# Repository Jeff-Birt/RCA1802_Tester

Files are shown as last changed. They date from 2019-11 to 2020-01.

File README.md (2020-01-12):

# RCA1802_Tester
Using an Aruino Mega 2560 to test RCA/Harris/Intersil 1802 processors

I boughtt a batch of old RCA 1802 micro-processors from C.H. Ina & Company on eBay. When they showed up it was obvious that had been sanded and re-labeled. The rest of the parts for the project I wanted them for had not arrived and I wanted to test them before complaining.

I had an Arduino Mega 2560 sitting on the bench and thought I would try to use it to test the 1802s. This project is the result of that effort...

NOTE:
 PCB Design, button handling code, and EF randomization code from: Hans Liss, Thanks Hans!

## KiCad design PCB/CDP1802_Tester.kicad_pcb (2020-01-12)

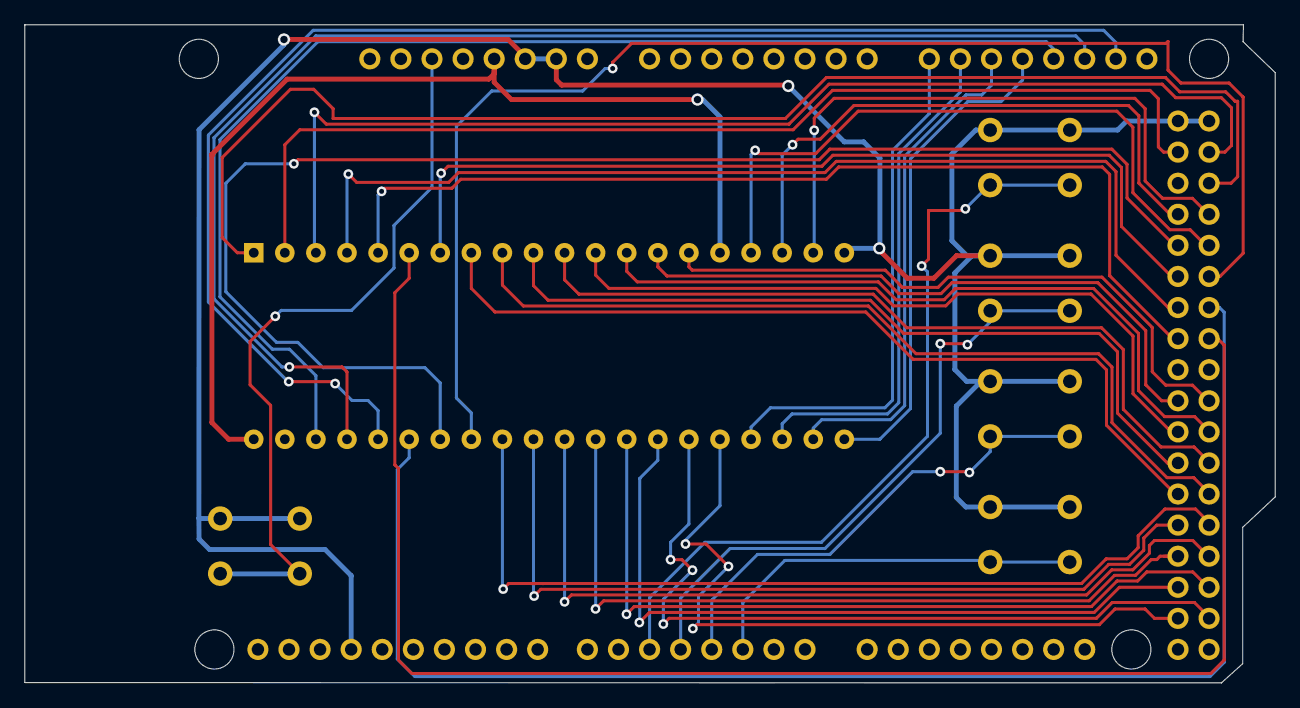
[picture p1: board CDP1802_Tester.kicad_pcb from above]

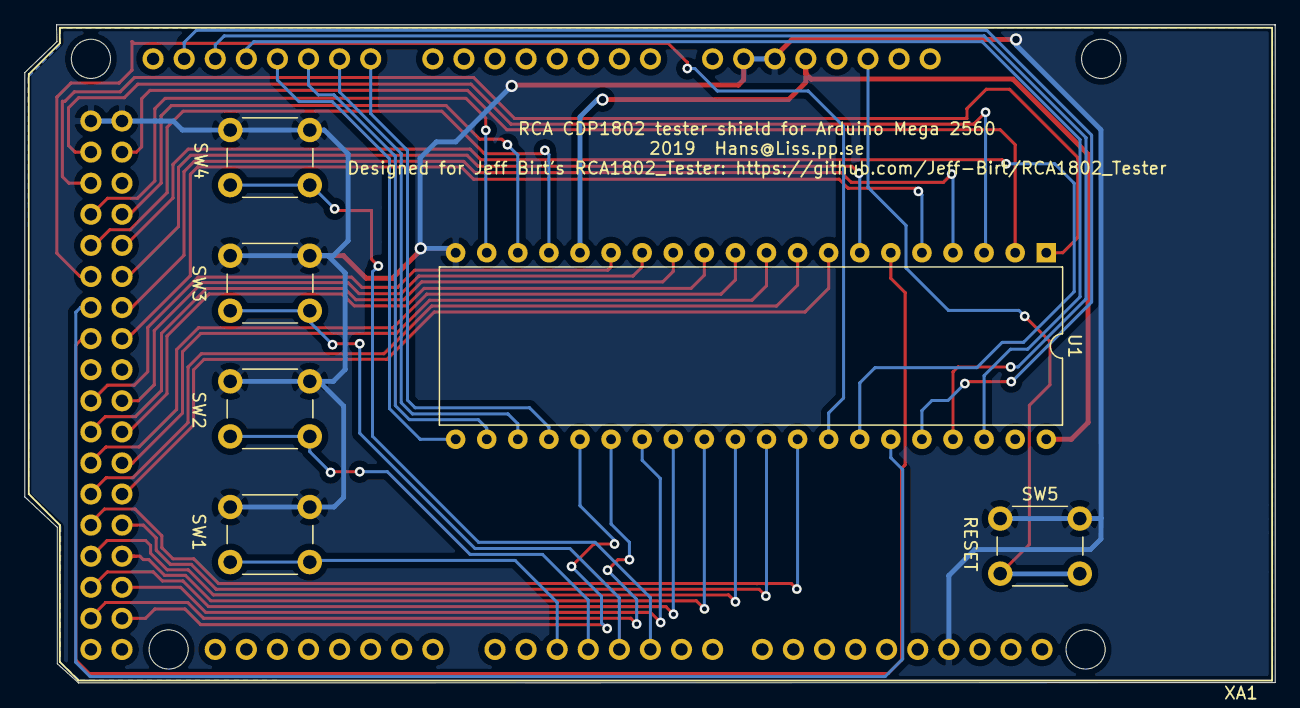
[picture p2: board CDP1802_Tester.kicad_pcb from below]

Board: 2 copper layers, 102.2 x 53.8 mm, 7 parts (7 on the bottom side), 43 nets.

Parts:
SW1, SW2, SW3, SW4, SW5: SW_Push; SW_PUSH_6mm
U1: CDP1802ACE; DIP-40_W15.24mm
XA1: Arduino_Mega2560_Shield_alt1

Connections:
/CLEAR: U1.3, XA1.D53
/CLOCK: U1.1, XA1.D51
/D0: U1.15, XA1.D37
/D1: U1.14, XA1.D36
/D2: U1.13, XA1.D35
/D3: U1.12, XA1.D34
/D4: U1.11, XA1.D33
/D5: U1.10, XA1.D32
/D6: U1.9, XA1.D31
/D7: U1.8, XA1.D30
/DMA_IN: U1.38, XA1.A12
/DMA_OUT: U1.37, XA1.A13
/EF1: U1.24, XA1.A8
/EF2: U1.23, XA1.A9
/EF3: U1.22, XA1.A10
/EF4: U1.21, XA1.A11
/INTERRUPT: U1.36, XA1.A14
/MA0: U1.25, XA1.D22
/MA1: U1.26, XA1.D23
/MA2: U1.27, XA1.D24
/MA3: U1.28, XA1.D25
/MA4: U1.29, XA1.D26
/MA5: U1.30, XA1.D27
/MA6: U1.31, XA1.D28
/MA7: U1.32, XA1.D29
/MRD: U1.7, XA1.D44
/MWR: U1.35, XA1.D43
/N0: U1.19, XA1.D49
/N1: U1.18, XA1.D48
/N2: U1.17, XA1.D47
/Q: U1.4, XA1.D42
/SC0: U1.6, XA1.D41
/SC1: U1.5, XA1.D40
/TPA: U1.34, XA1.D46
/TPB: U1.33, XA1.D45
/WAIT: U1.2, XA1.D52
GND: SW1.2, SW2.2, SW3.2, SW4.2, SW5.1, U1.20, XA1.GND1, XA1.GND2, XA1.GND3, XA1.GND5, XA1.GND6
unnamed: SW1.1, XA1.D2
unnamed: SW2.1, XA1.D3
unnamed: SW3.1, XA1.D4
unnamed: SW4.1, XA1.D5
unnamed: SW5.2, XA1.RST1
VCC: U1.16, U1.40, XA1.5V1

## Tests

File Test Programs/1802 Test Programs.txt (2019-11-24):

LDI 0x0F
PLO R(1).0
LDI 0x00
PHI R(1).1
SEX R1
LDI 0x55
STR R1

// Memory store --- Load D with 0x55 store to Address pointed to by R(1)
// virtual system RAM, 0x0000 to 0x0039 ->
byte virtRAM[] =  { 0xF8, 0x0F, 0xA1, 0xF8, 0x00, 0xB1, 0xE1, 0xF8,
					0x55, 0x51, 0xC4, 0xC4, 0xC4, 0xC4, 0xC4, 0xC4,
					0xC4, 0xC4, 0xC4, 0xC4, 0xC4, 0xC4, 0xC4, 0xC4,
					0xC4, 0xC4, 0xC4, 0xC4, 0xC4, 0xC4, 0xC4, 0xC4,
					0xC4, 0xC4, 0xC4, 0xC4, 0xC4, 0xC4, 0xC4, 0xC4,
					0xC4, 0xC4, 0xC4, 0xC4, 0xC4, 0xC4, 0xC4, 0xC4,
					0xC4, 0xC4, 0xC4, 0xC4, 0xC4, 0xC4, 0xC4, 0xC4,
					0xC4, 0xC4, 0xC4, 0xC4, 0xC4, 0xC4, 0xC4, 0xC4 };

LDI 0x0F
PLO R(1).0
LDI 0x00
PHI R(1).1
SEX R1
OUT 1

// I/O Output --- Set R(1)=0x000F, Set X=R(1), Mem @ R(1) output to data bus
// N0, N1, N2 indicate the lower nibble of the 6N Output instruction
// virtual system RAM, 0x0000 to 0x0039 -> 
byte virtRAM[] =  { 0xF8, 0x0F, 0xA1, 0xF8, 0x00, 0xB1, 0xE1, 0x61,
					0xC4, 0xC4, 0xC4, 0xC4, 0xC4, 0xC4, 0xC4, 0x55,
					0xC4, 0xC4, 0xC4, 0xC4, 0xC4, 0xC4, 0xC4, 0xC4,
					0xC4, 0xC4, 0xC4, 0xC4, 0xC4, 0xC4, 0xC4, 0xC4,
					0xC4, 0xC4, 0xC4, 0xC4, 0xC4, 0xC4, 0xC4, 0xC4,
					0xC4, 0xC4, 0xC4, 0xC4, 0xC4, 0xC4, 0xC4, 0xC4,
					0xC4, 0xC4, 0xC4, 0xC4, 0xC4, 0xC4, 0xC4, 0xC4,
					0xC4, 0xC4, 0xC4, 0xC4, 0xC4, 0xC4, 0xC4, 0xC4 };

LDI 0x0F
PLO R(1).0
LDI 0x00
PHI R(1).1
SEX R1
INP 1

// I/O Input --- Set R(1)=0x000F, Set X=R(1), Input from data bus to Mem @ R(1)
// N0, N1, N2 indicate the lower nibble of the 6N Output instruction
// virtual system RAM, 0x0000 to 0x0039 -> 
byte virtRAM[] =  { 0xF8, 0x0F, 0xA1, 0xF8, 0x00, 0xB1, 0xE1, 0x69,
					0xC4, 0xC4, 0xC4, 0xC4, 0xC4, 0xC4, 0xC4, 0x55,
					0xC4, 0xC4, 0xC4, 0xC4, 0xC4, 0xC4, 0xC4, 0xC4,
					0xC4, 0xC4, 0xC4, 0xC4, 0xC4, 0xC4, 0xC4, 0xC4,
					0xC4, 0xC4, 0xC4, 0xC4, 0xC4, 0xC4, 0xC4, 0xC4,
					0xC4, 0xC4, 0xC4, 0xC4, 0xC4, 0xC4, 0xC4, 0xC4,
					0xC4, 0xC4, 0xC4, 0xC4, 0xC4, 0xC4, 0xC4, 0xC4,
					0xC4, 0xC4, 0xC4, 0xC4, 0xC4, 0xC4, 0xC4, 0xC4 };

REQ
LDI 0x10
PLO R(1).0
LDI 0x00
PHI R(1).1
DEC R1
GLO R1
BNZ 0x07
BQ  0x00
SEQ
BR  0x01

// Q blink --- Q off, load 0x0010 to R(1)
// virtual system RAM, 0x0000 to 0x0039 -> 
byte virtRAM[] = {	0x7A, 0xF8, 0x10, 0xA1, 0xF8, 0x00, 0xB1, 0x21,
					0x81, 0x3A, 0x07, 0x31, 0x00, 0x7B, 0x30, 0x01,
					0xC4, 0xC4, 0xC4, 0xC4, 0xC4, 0xC4, 0xC4, 0xC4, 
					0xC4, 0xC4, 0xC4, 0xC4, 0xC4, 0xC4, 0xC4, 0xC4, 
					0xC4, 0xC4, 0xC4, 0xC4, 0xC4, 0xC4, 0xC4, 0xC4, 
					0xC4, 0xC4, 0xC4, 0xC4, 0xC4, 0xC4, 0xC4, 0xC4, 
					0xC4, 0xC4, 0xC4, 0xC4, 0xC4, 0xC4, 0xC4, 0xC4, 
					0xC4, 0xC4, 0xC4, 0xC4, 0xC4, 0xC4, 0xC4, 0xC4 };

00	F8 22	LDI 0x0F
02	A1		PLO R(1).0
03	F8 00	LDI 0x00
05	B1		PHI R(1).1
06	E1		SEX R1
07	34 11	B1 	0x11	'EF1
09	35 15	B2	0x15	'EF2
0B	36 19	B3	0x19	'EF3
0D	37 1D	B4	0x1D	'EF4
0F	30 07	BR  0x07
11	F8 01	LDI	0x01
13	30 1F	BR	0x1F	'OUTPUT
15	F8 02	LDI 0x02
17	30 1F	BR 	0x1F	'OUTPUT
19	F8 03	LDI 0x03
1B	30 1F	BR	0x1F	'OUTPUT
1D	F8 04	LDI	0x04
1F	51		STR R1		'OUTPUT
20	30 07	BR	0x07

// EFx input test -- output EF input # to Memory @ 0x22
// virtual system RAM, 0x0000 to 0x0039 -> 
byte virtRAM[] = {	0xF8, 0x22, 0xA1, 0xF8, 0x00, 0xB1, 0xE1, 0x34,
					0x11, 0x35, 0x15, 0x36, 0x19, 0x37, 0x1D, 0x30,
					0x07, 0xF8, 0x01, 0x30, 0x1F, 0xF8, 0x02, 0x30, 
					0x1F, 0xF8, 0x03, 0x30, 0x1F, 0xF8, 0x04, 0x51, 
					0x30, 0x07, 0xC4, 0xC4, 0xC4, 0xC4, 0xC4, 0xC4, 
					0xC4, 0xC4, 0xC4, 0xC4, 0xC4, 0xC4, 0xC4, 0xC4, 
					0xC4, 0xC4, 0xC4, 0xC4, 0xC4, 0xC4, 0xC4, 0xC4, 
					0xC4, 0xC4, 0xC4, 0xC4, 0xC4, 0xC4, 0xC4, 0xC4 };

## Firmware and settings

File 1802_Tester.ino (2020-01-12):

/*
 Simple test program for RCA 1802 microprocessor
 Jeffrey T. Birt (Hey Birt!)
 website: http://www.soigeneris.com
 YouTube: http://www.youtube.com/c/HeyBirt

 PCB Design, button handling code, and EF ran. from: Hans Liss, Thanks Hans!
*/

// NOTES: Uses a Arduino Mega 2560
// control /CLR and /WAIT 
// what should the settings for debug view levels be?
// A) full instruction cycle
// B) every half clock
// C) memory read/write
// D) I/O input/output

#include "1802_Tester.h"

// Arduino system states
enum SYS_STATE
{
	SYS_INIT,		// Initialized I/O, do start delay
	SYS_RESET,		// RESET mode: /CLEAR  WAIT
	SYS_PAUSE,		// PAUSE mode:  CLEAR /WAIT
	SYS_RUN,		// RUN mode:    CLEAR  WAIT
	SYS_STEP,		// Process one opcocde then STOP mode
	SYS_STOP		// stock clock
};

// States the control singnals can be in
enum SIGNAL_STATE
{
	SIG_LOW,
	SIG_RISING,
	SIG_HIGH,
	SIG_FALLING
};

enum DEBUG_STATE
{
	DB_OFF,
	DB_MININUM,
	DB_VERBOSE
};

#pragma region "1802 Test Programs"

// Memory store --- Load D with 0x55 store to Address pointed to by R(1)
// virtual system RAM, 0x0000 to 0x0039 ->
//byte virtRAM[] =  { 0xF8, 0x0F, 0xA1, 0xF8, 0x00, 0xB1, 0xE1, 0xF8,
//					0x55, 0x51, 0xC4, 0xC4, 0xC4, 0xC4, 0xC4, 0xC4,
//					0xC4, 0xC4, 0xC4, 0xC4, 0xC4, 0xC4, 0xC4, 0xC4,
//					0xC4, 0xC4, 0xC4, 0xC4, 0xC4, 0xC4, 0xC4, 0xC4,
//					0xC4, 0xC4, 0xC4, 0xC4, 0xC4, 0xC4, 0xC4, 0xC4,
//					0xC4, 0xC4, 0xC4, 0xC4, 0xC4, 0xC4, 0xC4, 0xC4,
//					0xC4, 0xC4, 0xC4, 0xC4, 0xC4, 0xC4, 0xC4, 0xC4,
//					0xC4, 0xC4, 0xC4, 0xC4, 0xC4, 0xC4, 0xC4, 0xC4 };


// I/O Output --- Set R(1)=0x000F, Set X=R(1), Mem @ R(1) output to data bus
// N0, N1, N2 indicate the lower nibble of the 6N Output instruction
// virtual system RAM, 0x0000 to 0x0039 -> 
//byte virtRAM[] =  { 0xF8, 0x0F, 0xA1, 0xF8, 0x00, 0xB1, 0xE1, 0x61,
//					0xC4, 0xC4, 0xC4, 0xC4, 0xC4, 0xC4, 0xC4, 0x55,
//					0xC4, 0xC4, 0xC4, 0xC4, 0xC4, 0xC4, 0xC4, 0xC4,
//					0xC4, 0xC4, 0xC4, 0xC4, 0xC4, 0xC4, 0xC4, 0xC4,
//					0xC4, 0xC4, 0xC4, 0xC4, 0xC4, 0xC4, 0xC4, 0xC4,
//					0xC4, 0xC4, 0xC4, 0xC4, 0xC4, 0xC4, 0xC4, 0xC4,
//					0xC4, 0xC4, 0xC4, 0xC4, 0xC4, 0xC4, 0xC4, 0xC4,
//					0xC4, 0xC4, 0xC4, 0xC4, 0xC4, 0xC4, 0xC4, 0xC4 };


// I/O Input --- Set R(1)=0x000F, Set X=R(1), Input from data bus to Mem @ R(1)
// N0, N1, N2 indicate the lower nibble of the 6N Output instruction
// virtual system RAM, 0x0000 to 0x0039 -> 
//byte virtRAM[] =  { 0xF8, 0x0F, 0xA1, 0xF8, 0x00, 0xB1, 0xE1, 0x69,
//					0xC4, 0xC4, 0xC4, 0xC4, 0xC4, 0xC4, 0xC4, 0x55,
//					0xC4, 0xC4, 0xC4, 0xC4, 0xC4, 0xC4, 0xC4, 0xC4,
//					0xC4, 0xC4, 0xC4, 0xC4, 0xC4, 0xC4, 0xC4, 0xC4,
//					0xC4, 0xC4, 0xC4, 0xC4, 0xC4, 0xC4, 0xC4, 0xC4,
//					0xC4, 0xC4, 0xC4, 0xC4, 0xC4, 0xC4, 0xC4, 0xC4,
//					0xC4, 0xC4, 0xC4, 0xC4, 0xC4, 0xC4, 0xC4, 0xC4,
//					0xC4, 0xC4, 0xC4, 0xC4, 0xC4, 0xC4, 0xC4, 0xC4 };


// EFx input test -- output EF input # to Memory @ 0x22
// virtual system RAM, 0x0000 to 0x0039 -> 
byte virtRAM[] = {  0xF8, 0x22, 0xA1, 0xF8, 0x00, 0xB1, 0xE1, 0x34,
					0x11, 0x35, 0x15, 0x36, 0x19, 0x37, 0x1D, 0x30,
					0x07, 0xF8, 0x01, 0x30, 0x1F, 0xF8, 0x02, 0x30,
					0x1F, 0xF8, 0x03, 0x30, 0x1F, 0xF8, 0x04, 0x51,
					0x30, 0x07, 0xC4, 0xC4, 0xC4, 0xC4, 0xC4, 0xC4,
					0xC4, 0xC4, 0xC4, 0xC4, 0xC4, 0xC4, 0xC4, 0xC4,
					0xC4, 0xC4, 0xC4, 0xC4, 0xC4, 0xC4, 0xC4, 0xC4,
					0xC4, 0xC4, 0xC4, 0xC4, 0xC4, 0xC4, 0xC4, 0xC4 };

// Q blink --- Q off, load 0x0010 to R(1)
// virtual system RAM, 0x0000 to 0x0039 -> 
//byte virtRAM[] = {	0x7A, 0xF8, 0x10, 0xA1, 0xF8, 0x00, 0xB1, 0x21,
//					0x81, 0x3A, 0x07, 0x31, 0x00, 0x7B, 0x30, 0x01,
//					0xC4, 0xC4, 0xC4, 0xC4, 0xC4, 0xC4, 0xC4, 0xC4, 
//					0xC4, 0xC4, 0xC4, 0xC4, 0xC4, 0xC4, 0xC4, 0xC4, 
//					0xC4, 0xC4, 0xC4, 0xC4, 0xC4, 0xC4, 0xC4, 0xC4, 
//					0xC4, 0xC4, 0xC4, 0xC4, 0xC4, 0xC4, 0xC4, 0xC4, 
//					0xC4, 0xC4, 0xC4, 0xC4, 0xC4, 0xC4, 0xC4, 0xC4, 
//					0xC4, 0xC4, 0xC4, 0xC4, 0xC4, 0xC4, 0xC4, 0xC4 };

// NOP test - Simple NOP test, address should increase
// virtual system RAM, 0x0000 to 0x0039 -> 
//byte virtRAM[] = {	0xC4, 0xC4, 0xC4, 0xC4, 0xC4, 0xC4, 0xC4, 0xC4,
//					0xC4, 0xC4, 0xC4, 0xC4, 0xC4, 0xC4, 0xC4, 0xC4,
//					0xC4, 0xC4, 0xC4, 0xC4, 0xC4, 0xC4, 0xC4, 0xC4, 
//					0xC4, 0xC4, 0xC4, 0xC4, 0xC4, 0xC4, 0xC4, 0xC4, 
//					0xC4, 0xC4, 0xC4, 0xC4, 0xC4, 0xC4, 0xC4, 0xC4, 
//					0xC4, 0xC4, 0xC4, 0xC4, 0xC4, 0xC4, 0xC4, 0xC4, 
//					0xC4, 0xC4, 0xC4, 0xC4, 0xC4, 0xC4, 0xC4, 0xC4, 
//					0xC4, 0xC4, 0xC4, 0xC4, 0xC4, 0xC4, 0xC4, 0xC4 };

#pragma endregion "1802 Test Programs"

// gloabls
int Start_Delay = 0;		// delay reset release 64 half clocks after start
unsigned int Address16 = 0; // used to latch in full 16-bit address
unsigned int clkCount = 0;	// counts in 1/2 clock cycles
SYS_STATE sysState = SYS_INIT;
SIGNAL_STATE MRD_State = SIG_LOW;
SIGNAL_STATE MWR_State = SIG_LOW;
SIGNAL_STATE TPA_State = SIG_LOW;
SIGNAL_STATE TPB_State = SIG_LOW;
DEBUG_STATE debugState = DB_MININUM;

byte newPORTA = 0; byte oldPORTA = 0;	// not sure if oldPORTA actually needed
byte newPORTL = 0; byte oldPORTL = 0;	// track old state, compare to new for rising/falling edges
byte newSCx = 0; 						// new state of SC0 adn SC1

unsigned long debounceDelay = 50;    // the debounce time; increase if the output flickers

// Initalize the Arduino I/O ports, start serial coms
// Leave processer in RESET mode: /CLEAR WAIT
void setup()
{
	PORTA = PORTA & ~ADD_BUS;	  // all pins low for HIZ
	PORTB = ( PORTB & ~(CLEAR | CLOCK) ) | WAIT; // set to reset mode
	PORTC = PORTC & ~DATA_BUS;	  // all pins low for HIZ
	PORTG = PORTG & ~(SC0 | SC1); // all pins low for HIZ
	PORTK = PORTK | (EF1 | EF2 | EF3 | EF4 | DMA_IN | DMA_OUT | INTERRUPT); // all pins HI/off
	PORTL = PORTL & ~(N0 | N1 | N2 | TPA | TPB | MRD | MWR | Q); // all pins low for HIZ

	DDRA = ~ADD_BUS;	// all inputs, HIZ at this point
	DDRB = CLEAR | WAIT | CLOCK; // outputs
	DDRC = ~DATA_BUS;	// all inputs, HIZ at this point
	DDRG = DDRG & ~(SC0 | SC1);  // inputs, HIZ at this point
	DDRK = EF1 | EF2 | EF3 | EF4 | DMA_IN | DMA_OUT | INTERRUPT; // outputs, all HI at this point
	DDRL = ~(N0 | N1 | N2 | TPA | TPB | MRD | MWR | Q); // all inputs, HIZ at this point

	initButtons();

	Serial.begin(19200); // open the serial port at 9600 bps:
	Serial.println("Starting...");
}


// Start up in RESET mode, start clock, after 64 clocks put in PAUSE mode
// Clock count only incremetned in RUN mode.
void loop()
{
	readButtons();
	// watch for input from user here, using a blocking read for now
	if (Serial.available())
	{
		String command = Serial.readStringUntil('\n');
		cmdDecode(command);
	}

	if (sysState == SYS_RUN)
	{
		if (hasButtonPressEvent(0)) {
			randomize_ef();
		}
    
		// read in current state of I/O
		newPORTA = PINA;			 // 1802 address bus
		newPORTL = PINL;			 // 1802 status outputs
		newSCx = PING & (SC0 | SC1); // 1802 state outputs

		// (A) Decode state of control signals
		stateDecode();

		// (B) Address latch, rising edge TPA latch MSB, rising edge TPB latch LSB
		if (TPA_State == SIG_RISING)
		{
			Address16 = newPORTA;
			//logState("TPA");
		} 
		else if (TPB_State == SIG_RISING)
		{
			Address16 = (Address16 << 8) | newPORTA;
			//logState("TPB");
		}

		// (C) if rising edge of /MRD or /MWR then set data bus to input from 1802
		if ((MRD_State == SIG_RISING) | (MWR_State == SIG_RISING))
		{
			portC_ModeInput();
			logState("Data bus Input");
		}

		// (D) TPB rising edge, reading (Arduino to 1802), or writing (1802 to Arduino)
		// if /MRD low Arduino writing to data bus, 1802 reading from memory
		// Arduino reading data from data bus, i.e. 1802 is writing to virtual memory
		if (TPB_State == SIG_RISING)
		{
			if (MRD_State == SIG_LOW)
			{
				portC_ModeOutput();

				if (Address16 < 64)
				{
					portC_OutputValue(virtRAM[Address16]);
					logState("1802 Memory Read");
				}
				else
				{
					portC_OutputValue(0xC4); // NOP
					logState("NOP");
				}
			}
			else if (MWR_State == SIG_LOW)
			{
				byte fromDataBus = portC_InputValue();
				if (Address16 < 64)
				{
					virtRAM[Address16] = fromDataBus;
				}
				logState(String(fromDataBus, HEX) + " 1802 Memory Write");
			}
		}

		// (E) reading or writing to I/O port if N0~N2 raised and
		// /MRW falling edge indicates input from Arduino to 1802, 
		// /MRD and TPB rising edge indicates output from 1802 to Arduino
		if (newPORTL & (N0 | N1 | N2))
		{
			if (MWR_State == SIG_FALLING)
			{
				portC_ModeOutput();
				portC_OutputValue(0xAA); // fixed value at this point
				logState(" I/O Input");
			}
			else if (MRD_State == SIG_LOW && TPB_State == SIG_RISING)
			{
				byte fromDataBus = portC_InputValue();
				logState(String(fromDataBus, HEX) + " I/O Output");
			}
		}

		// (F) Is Q rising or falling?
		if ((newPORTL & Q) && !(oldPORTL & Q))
		{
			logState("Q turned on");
		}
		else if (!(newPORTL & Q) && (oldPORTL & Q))
		{
			logState("Q turned off");
		}

		delay(100);				// delay for serial debug display
		clkCount++;				// inc clock 1/2 tick
		oldPORTA = newPORTA;	// not sure I need to save address bus
		oldPORTL = newPORTL;	// save new values for comparison next cycle
	}
	else if (sysState == SYS_INIT)
	{
		Start_Delay++;
		if (Start_Delay > 63)
		{
			//PORTB = PORTB | CLEAR;  // PAUSE mode:  CLEAR /WAIT
			//PORTB = PORTB & ~WAIT;	//
			//sysState = SYS_PAUSE;
			//Serial.println("");
			//Serial.println("Pause Mode");
			cmdDecode("pause");
		}
	}

	if (sysState != SYS_STOP)
	{
		PORTB = PORTB ^ CLOCK; // toggle clock 1/2 tick
	}
}

// Decodes state (rising/falling/steady) of control signals
void stateDecode()
{
	if (newPORTL & TPA)
	{
		TPA_State = (!(oldPORTL & TPA)) ? SIG_RISING : SIG_HIGH;
	}
	else
	{
		TPA_State = (oldPORTL & TPA) ? SIG_FALLING : SIG_LOW;
	}

	if (newPORTL & TPB)
	{
		TPB_State = (!(oldPORTL & TPB)) ? SIG_RISING : SIG_HIGH;
	}
	else
	{
		TPB_State = (oldPORTL & TPB) ? SIG_FALLING : SIG_LOW;
	}

	if (newPORTL & MRD)
	{
		MRD_State = (!(oldPORTL & MRD)) ? SIG_RISING : SIG_HIGH;
		//logState("MRD " + String((MRD_State == SIG_RISING)?"RISING":"HIGH"));
	}
	else
	{
		MRD_State = (oldPORTL & MRD) ? SIG_FALLING : SIG_LOW;
		//logState("MRD " + String((MRD_State == SIG_FALLING)?"FALLING":"LOW"));
	}

	if (newPORTL & MWR)
	{
		MWR_State = (!(oldPORTL & MWR)) ? SIG_RISING : SIG_HIGH;
		//logState("MWR " + String((MWR_State == SIG_RISING)?"RISING":"HIGH"));
	}
	else
	{
		MWR_State = (oldPORTL & MWR) ? SIG_FALLING : SIG_LOW;
		//logState("MWR " + String((MWR_State == SIG_FALLING)?"FALLING":"LOW"));
	}
}

// wonder if this should be used for changing states as well?
void cmdDecode(String command)
{
	if (command == "load")
	{
		// Control bits: /CLEAR /WAIT
		Serial.println();
		Serial.println("Load Mode");
	}
	else if (command == "reset")
	{
		PORTB = PORTB & ~CLEAR; // RESET mode:  /CLEAR WAIT
		PORTB = PORTB | WAIT;	//
		sysState = SYS_RESET;

		Serial.println();
		Serial.println("Reset Mode");
	}
	else if (command == "pause")
	{
		PORTB = PORTB | CLEAR;  // PAUSE mode:  CLEAR /WAIT
		PORTB = PORTB & ~WAIT;	//
		sysState = SYS_PAUSE;
		Serial.println();
		Serial.println("Pause Mode");
	}
	else if (command == "run")
	{
		// start clock so processor and/or set to RUN mode
		PORTB = PORTB | CLEAR;  // RUN mode:  CLEAR WAIT
		PORTB = PORTB | WAIT;	//
		sysState = SYS_RUN;

		Serial.println();
		Serial.println("Run mode");
		Serial.println("Clk \tSCx \tCW_CL \tPORTL \tAdd \tData \tNote");
	}
	else if (command == "stop")
	{
		// stop clock so processor stops
		sysState = SYS_STOP;
		Serial.println();
		Serial.println("System is Stopped");
	}
	else if (command == "dump")
	{
		// stop processor and dump virtual memory
		Serial.println();
		Serial.println("Memory dump 0x0000 to 0x0039");
		sysState = SYS_STOP;
		for (int row = 0; row < 8; row++)
		{
			for (int col = 0; col < 8; col++)
			{
				Serial.print(intToHex(virtRAM[row * 8 + col], 2));
				Serial.print(" ");
			}
			Serial.println();
		}
		Serial.println();
		Serial.println("System is Stopped");
		Serial.println();
	}
	else if (command == "status")
	{
		// stop processor and show current processor status
		// maybe combine with stop command
		Serial.println();
		Serial.println("Current Status");
		Serial.println("Clk \tSCx \tCW_CL \tPORTL \tAdd \tData \tNote");
		logState("status");
		sysState = SYS_STOP;
	}
	else if (command == "help")
	{
		Serial.println();
		Serial.println("List of commands");
		Serial.println("load   - not supported");
		Serial.println("reset  - processor in RESET mode");
		Serial.println("pause  - processor in PAUSE mode");
		Serial.println("run    - processor in RUN mode");
		Serial.println("stop   - stop clock");
		Serial.println("dump   - dump vertual memory");
		Serial.println("status - display status, stop");
	}

}


#pragma region "Button handling code"

void readButton(int bNo) 
{
	int reading = digitalRead(buttons[bNo]);
	// If the switch changed, due to noise or pressing:
	if (reading != lastButtonState[bNo]) 
	{
		// reset the debouncing timer
		lastDebounceTime[bNo] = millis();
	}

	if ((millis() - lastDebounceTime[bNo]) > debounceDelay) 
	{
		// whatever the reading is at, it's been there for longer than the debounce
		// delay, so take it as the actual current state:

		// if the button state has changed:
		if (reading != buttonState[bNo]) 
		{
			buttonState[bNo] = reading;
			isButtonRead[bNo] = false;
		}
	}
	lastButtonState[bNo] = reading;
}

void readButtons() {
	for (int i = 0; i < NBUTTONS; i++) {
		readButton(i);
	}
}

void initButtons() {
	for (int i = 0; i < NBUTTONS; i++) {
		pinMode(buttons[i], INPUT_PULLUP);
		buttonState[i] = HIGH;
		lastButtonState[i] = HIGH;
		isButtonRead[i] = true;
	}
}

boolean hasButtonPressEvent(int bNo) {
	if (buttonState[bNo] == LOW && !isButtonRead[bNo]) {
		isButtonRead[bNo] = true;
		return true;
	}
	else {
		return false;
	}
}

#pragma endregion "Button handling code"


#pragma region "Data Bus PORTC Helpers"

// set data bus to HIZ input mode
void portC_ModeInput(void)
{
	DDRC = ~DATA_BUS;			// change direction to all inputs
	PORTC = PORTC & ~DATA_BUS;	// all pins low for HIZ
}

// input byte from data bus
byte portC_InputValue(void)
{
	return PINC;
}

// set data bus to output mode
void portC_ModeOutput(void)
{
	DDRC = DATA_BUS;	// change direction to outputs
}

// output a byte on the data bus
void portC_OutputValue(byte value)
{
	PORTC = value;		// set value to output
}

#pragma endregion "Data Bus PORTC Helpers"

void randomize_ef() {
	int rval = random(0, 5), ef;
	if (rval == 4) {
		ef = 0;
		Serial.println("No EF pin set.");
	}
	else {
		ef = 1 << rval;
		Serial.println("EF pin " + String(rval + 1) + " set.");
	}
	PORTK = (PORTK & ~(EF1 | EF2 | EF3 | EF4)) | ~ef;
}

// helper to dump current state out to serial port
void logState(String note)
{
	//Serial.println("Clk \tSCx \tCW_CL \tPORTL \tAdd \tData \tNote");
	if (debugState != DB_OFF)
	{
		Serial.print(intToHex(clkCount, 4)); Serial.print("\t");
		Serial.print(newSCx); Serial.print("\t");
		Serial.print(intToHex(PORTC & (CLEAR | WAIT | CLOCK), 2)); Serial.print("\t");
		Serial.print(intToHex(newPORTL, 2)); Serial.print("\t");
		Serial.print(intToHex(Address16, 4)); Serial.print("\t");
		Serial.print(intToHex(PINC, 2)); Serial.print("\t");
		Serial.println(note);
	}
}

// Returns string representation of int in HEX with leading zeros
// value: int to convert, places: number of digits padded with leading zeros
String intToHex(int value, int places)
{
	String hexString = "000"+ String(value, HEX);
	hexString.toUpperCase();	// make sure all upper case
	int length = hexString.length();
	if ( length > places) { hexString.remove(0, length - places); }
	return hexString;  // make sure only 2 chars long
}

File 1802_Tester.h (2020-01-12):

#pragma once

// PORT A (inputs to Arduino)
#define ADD_BUS		0xFF	// well, the address bus of course

// PORT B (Outputs from Arduino)
// /CLEAR	/WAIT	MODE (1802)
//	L		L		LOAD
//	L		H		RESET
//	H		L		PAUSE
//	H		H		RUN
#define CLEAR		0x01	// active low
#define WAIT		0x02	// active Low
#define CLOCK		0x04	// Clock input, active low

// PORT C (bi-directional)
#define DATA_BUS	0xFF	// well, the data bus of course

//PORT G (inputs to Arduino)
#define SC0			0x01	// SC0==0->Fetch, SC0==1->Execute
#define SC1			0x02	// 

// PORT K (Outputs from Arduino)
#define EF1			0x01	// EF1 Input
#define EF2			0x02	// EF2 Input
#define EF3			0x04	// EF3 Input
#define EF4			0x08	// EF4 Input
#define DMA_IN		0x10	// DMA Input mode flag
#define DMA_OUT		0x20	// DMA Output mode flag
#define INTERRUPT	0x40	// Interrupt input
//#define OPEN		0x80	// Not used

// PORT L (inputs to Arduino)
#define N0			0x01	// I/O Control Line 0
#define N1			0x02	// I/O Control Line 1
#define N2			0x04	// I/O Control Line 2
#define TPA			0x08	// Timing Pulse A, MSB of address
#define TPB			0x10	// Timing Pulse B, LSB of address
#define MRD			0x20	// Memory Read, active low
#define MWR			0x40	// Memory Write, active low
#define Q			0x80	// Q flip-flop output

#define BTN1 5				// buttons included on shield
#define BTN2 4				// these are Arduino pin numbers
#define BTN3 3
#define BTN4 2

void stateDecode();				// decode control signal state (rising/falling/steady) 
void cmdDecode(String command);	// decodes commands from serial port
void logState(String note);		// helper to dump current state out to serial port
void portC_ModeInput(void);		// set data bus to HIZ input mode
byte portC_InputValue(void);	// input byte from data bus
void portC_ModeOutput(void);	// set data bus to output mode
void portC_OutputValue(byte value); // output a byte on the data bus
String intToHex(int value, int places);	// convert int to hex padded #places

const int buttons[] = { BTN1, BTN2, BTN3, BTN4 };
#define NBUTTONS (sizeof(buttons)/sizeof(int))
int buttonState[NBUTTONS];
boolean isButtonRead[NBUTTONS];
int lastButtonState[NBUTTONS];
int lastDebounceTime[NBUTTONS];

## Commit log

2019-11-14 Can now run simple programs. Included a simple Q blink program.
    Still need to wire up N0-N2, EF1-EF4 and write 1802 code to test them.
2019-11-17 Have Input from I/O working now. Need to rework how the data bus direction is changed on the Arduino.
    [1802_Tester.ino]
2020-01-10 Added button code Fixed PORTK initialization bug
    [1802_Tester.ino]
2020-01-10 Added PCB KiCad project
    [CDP1802_Tester-B_CrtYd.gbr, CDP1802_Tester-B_Cu.gbr, CDP1802_Tester-B_Fab.gbr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]
2020-01-10 Added Device and Footprint libraries for the modified shield
    [CDP1802_Tester.sch]
